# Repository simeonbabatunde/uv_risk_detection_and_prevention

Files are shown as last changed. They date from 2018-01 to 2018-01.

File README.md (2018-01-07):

### UV Risk Detection and Alert System

#### Team UV
- Kristopher Kohm
- Simeon Babatunde
- Benjamin Coomes
- Miriam Lozneanu

#### System Description
The UV risk detection and alert system is a set of wearable devices that inform the user about UV exposure rate. One device senses UV radiation and the other displays the UV radiation levels. The display device shows the current and average UV index. The display is in the form of two LED bars that ‘fill up’ as exposure increases, and ‘empty’ as exposure decreases. The sensor device can be clipped onto a hat or backpack. The display device is worn on the user’s wrist. The system lets people know when they have experienced a healthy amount of radiation and when their exposure is approaching dangerous levels.

#### Image(s)
skype_picture 1

October 3, 2017

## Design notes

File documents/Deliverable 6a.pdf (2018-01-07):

Team | UV | - | Final | Report
Simeon Babatunde | sbabatu@g.clemson.edu
Benjamin Coomes | bcoomes@g.clemson.edu
Kristopher Kohm | kckohm@g.clemson.edu
Miriam Lozneanu | mloznea@g.clemson.edu
Project | Summary

Our system is a set of wearable devices that inform the user about UV exposure. One device senses UV radiation and the other displays UV radiation levels. The display device shows the current and average UV index. The display is in the form of two LED bars that ‘fill up’ as exposure increases, and ‘empty’ as exposure decreases. The sensor device can be clipped onto a hat or backpack. The display device is worn on the user’s wrist. Our system lets people know when they have experienced a healthy amount of radiation and when their exposure is approaching dangerous levels.

Project | Description | and | Implementation

Changes
- Battery - Originally the batteries for each component were going to be a series of coin cell batteries. This was changed to the Lithium Ion batteries used for the final project for three reasons, the first of which was rechargeability. Once the coin cell batteries ran out of power they would need to be replaced, but the Lithium Ion batteries could simply be recharged. The second reason was that we wanted an extra 0.1 Volts from our battery which the Lithium Ion batteries offered. The final reason was the capacity of the batteries, because the coin cell batteries would not have lasted nearly as long as the Lithium Ion batteries. The coin cell batteries offered 110mAh at 3.6 Volts, whereas the Lithium Ion batteries offered 1000 mAh at 3.7 Volts.
- Sensor Device Displays - Originally one of the sensor bars was supposed to display the instantaneous changes in UV levels and the other was supposed to display the total amount of radiation received since the device had been on. The instantaneous bar was kept the same, but the total bar was changed to an average amount of radiation received since the sensor device had been on. This was both more useful and computationally efficient because we did not have to worry about overflow from the total.

Software:
- Sensor Board - The sensor board runs a program that loops between three states: get UV index, compute average UV index, and transmit data. The UV index is calculated based on values read from the UV sensor. We found the algorithm to calculate the UV index as a part of the Sparkfun software library for the ZOPT2201 UV sensor. After getting the current UV index, it is used to calculate the average UV index from the time the sensing device has been on. Once the instantaneous and average UV index have been obtained, they are sent to the sensor board. Each message sent is only two bytes. The first byte contains the current UVI and the second contains the average UVI. Transmission is done using Josiah Hester’s CC1101 library.
- Display Board - The display board checks to see if any radio transmissions have been received every 100 ms. If a message has been received, the current UVI is retrieved from the first byte and the average UVI is retrieved from the second byte. The program then sets the LEDs on each LED bar according to the values received. We wrote an LedBar class to simplify controlling each LED bar.

Hardware
The following is the list of electronic components used in the implementation of our system:
- ZOPT2201 UV Sensor: this component was used in the sensing unit for sensing 310nm ultraviolet radiation (UVB). It gives accurate UV index measurement without interpolation from ambient light like most other sensors. It utilizes simple I

2C (Inter-Integrated Circuit) interface for communicating with the MSP430fr5969 microcontroller, and rated for 3.3V and 110μA. It uses dual Qwiic connectors for seamless connection.
- MSP430FR5969 Microcontroller: This is the major component used in both the sensing and display unit of the system. It is an ultra-low-power (ULP) FRAM platform, utilizing 16-bit RISC Architecture for up to 16-MHz clock. It is responsible for controlling and interfacing with other peripherals within the system. Powered by (1.8 V to 3.6 V) and consumes approximately 100µA/MHz. The first Microcontroller is responsible for fetching the sensed data from the UV sensor, compute the average UVB index and then transmit the data to the display unit via the CC1101 radio transceiver. The second microcontroller is responsible for retrieving transmitted data from the radio transceiver and then drives the display section based on the signals received.
- CC1101 Radio Transceiver: It is a low-cost sub-1GHz transceiver designed for very low-power wireless applications. It was used for initiating remote data transfer between the sensing and display module. It interfaces with both microcontrollers and operates in the frequency range 387 – 464 MHz with instantaneous maximum working current less than 30mA. It interfaces with the MSP430 microcontroller using Serial Peripheral Interface Bus (SPI).
- YSLB-10251B5-10 LED bar: This is a simple strip of 10 blue LEDs. Each LED is controlled directly by the microcontroller via the IO pins. Each LED operated between 3.2 and 3.6 V, with a maximum forward current of 20mA. We used two of these on our display board to indicate the current and average UV index. We used 330 Ohm resistors to drop the current to 10mA on each LED.
- Li-Ion Battery PRt-13813: These rechargeable Lithium Ion batteries offered 1000 mAh at 3.7 Volts. These were connected to the Vin pin of the Voltage Regulator which converts it into 3.3V. One was supplied for each unit and they could easily be attached and removed via headers on each board.
- NCP583 LDO Voltage Regulator: This was used on both units to regulate the 3.7V from the battery into 3.3V used to power the components.
- Resistor: We utilized a 330 ohms resistor for limiting the LED current to 10mA. Thus, minimizing the energy consumption of the system.
- Capacitor: We used both 1µF and 0.1µF as filtering capacitors at the input and output of the voltage regulator on both units.
- Surface Mount DPDT Switch: the switch was used as the main controller for switching the system ON/OFF. It is capable of switching up to 360mA at 3.3v.
Board | Pictures:

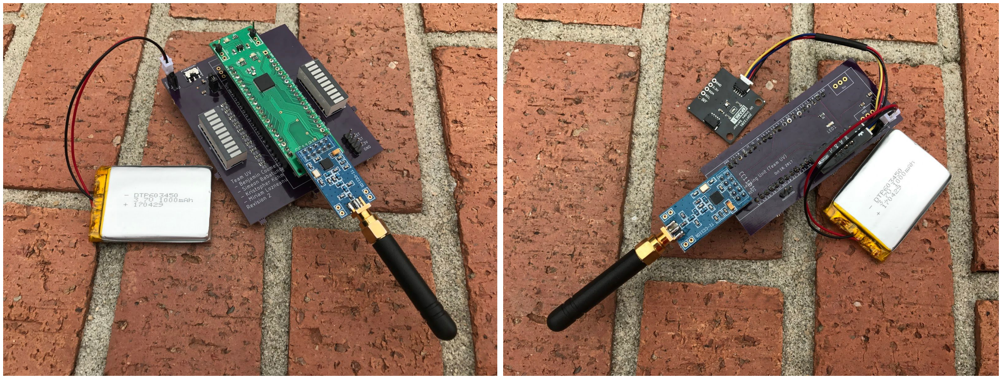
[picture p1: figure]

Display Board | Sensor Board

Challenges:
- Radios: The biggest challenge we faced during demonstrations was reliable radio communication. We did not perform any checks on received data, so interference and corrupted packets could cause our display device to malfunction. We could have solved this problem by establishing a session between the display and sensor boards before either begins sending or receiving data. A session key would be chosen and appended to the first byte of every message. Messages without this key would be ignored. We also should have checked the values of the UV indexes, and ignored any invalid values.
- Pin configurations: We wanted to use the green MSP430 boards since they already has an MSP430 chip soldered to them, as well as a place for the
CC1101 radio. However, we discovered that pin 3.6 was wired to the radio on the green board. We needed this pin for I2C communication with the UV sensor. We managed to move the pin by modifying the pins.h file in Josiah Hester’s CC1101 library. We also had to change Energia.h under energia-1.6.10E18\hardware\energia\msp430\cores\msp430 to add pin definitions to energia, since the green board exposes some pins that Energia does not define.

Resources
- Josiah Hester’s CC1101 library: This library provides a simple interface to the CC1101 radios that we used in our project. It can be found at the following buffet
repository: | https://buffet.cs.clemson.edu/vcs/u/jhester/cc1101-energia/. | We
modified the pin configuration slightly for the sensor board, since the library uses pin 3.6 by default, which we needed for the ZOPT2201 UV sensor. We also referred to the TX and RX examples included in this library when writing code for our devices.
- ZOPT2201 library: This library was developed by Nathan Seidle at Sparkfun. It contain the firmware and sample code for interfacing the ZOPT2201 UV sensor with the microcontroller via the I2C protocol. We customized the library by creating a .cpp version for energia which also contains the logic for computing the UVB average. The library can be found here: https://github.com/sparkfunX/Qwiic_UV_Sensor-ZOPT220x/tree/master/Firmwar e (https://github.com/sparkfunX/Qwiic_UV_Sensor-ZOPT220x/tree/master/Firmware)
Class | Feedback
What | was | the | most | challenging | part | of | this | class?
Ben: The most mentally challenging part was learning how to select parts that would work together and designing a circuit to connect them. The most challenging part overall was putting the accelerometer on the sensor board.

Simeon: The class on state machines and low power modes took me some time to comprehend.
Kristopher: Constructing a properly functioning sensor board (for the class, not the project) was fairly difficult. In addition, working with hardware for the first time is daunting coming from a Computer Science background.

Miriam: I used light traffic examples, but coding was hard for me. I tried to figure out how to get files on Energia working, but that was difficult too.

What | would | you | like | to | see | added | to | this | class | in | future | semesters?
Ben: I would like to see more pizza on demo day. Other than that, I can’t think of anything else to add.

Simeon: I would appreciate if a deadline is set earlier on in the semester for the assembling of the sensor board before taking the class on Accelerometry and signal processing. Also, having accelerometer with a bigger footprint would be fun to assemble.

Kristopher: I would like to do more hands on, in class demonstrations and activities. Perhaps more of them could rely on use of the red boards instead of the sensor boards in case people had trouble with them.

Miriam: I am interested in solar energy, and like to learn about it.

Free | response | on | the | class | in | general.
Ben: This was a fun and practical class. I think that I could build other similar embedded systems on my own now. Before this semester, I would have been too intimidated by putting hardware together to try.

Simeon: The class does not only cover the technical aspect of Embedded Systems, but also helps in developing interpersonal skills like teamwork, presentation, and creative thinking.

Kristopher: I appreciated not having to stress about exams in this class because that made it much more enjoyable to come to. Also, the Computer Science major does not offer many practical applications of hardware combined with software, so it was beneficial to see how these two important elements could come together.

Miriam: I enjoyed the class so far, and it gave me an great opportunity to learn about hardware and software.

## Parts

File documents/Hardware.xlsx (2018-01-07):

Name | VMAX | VMIN | I | URL | Price | Qty | total | Description/Notes
Qwicc UV Sensor - ZOPT2201 | 3.6V | 1.7V | .110 mA | https://www.sparkfun.com/products/14264 | $9.95 | 1 | 9.95 | UVB and ambient light sensing. Needs qwiic connections. 3.3V, I2C interface.
Coin Cell Battery 3.6v |  |  |  | https://www.sparkfun.com/products/10319 | $2.95 | 4 | 11.8 | 110mAh, rechargeable, each MCU will need one, and we want a spare for each MCU
Coin Cell Battey Holder |  |  |  | https://www.sparkfun.com/products/8863 | $0.95 | 2 | 1.9 | One for each battery
Li-Ion Battery PRt-13813 |  |  | 1000mAh
MSP430 MCU | 3.6V | 1.8V | 2.5mA | ?? | $0.00 | 2 | 0 | We will use the msp430s on the small green pcb
10 Segment LED Bar Graph | 3.6V | 3.2V | 20 mA | https://www.sparkfun.com/products/9937 | $1.95 | 2 | 3.9 | 3.2-2.6 V, used for output from UV sensor one blue one green
cc1101 Transciever | 3.6V | 1.8V | 15-40 mA | https://www.amazon.com/dp/B00U5TO37W?creative=395033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 | $15.40 | 2 | 30.8 | For radio communication
NCP583 | 6V |  |  | http://www.mouser.com/search/ProductDetail.aspx?r=863-NCP583SQ33T1G
100mm qwiic cable |  |  |  | https://www.sparkfun.com/products/14427 | $2.00 | 1 | 2 | for connecting the UV sensor to the board
qwiic adapter |  |  |  | https://www.sparkfun.com/products/14237 | $0.95 | 1 | 0.95 | qwiic to I2C conversion
Officemate Binder Clips |  |  |  | https://www.amazon.com/Officemate-Binder-Clips-Assorted-31022/dp/B007TR2DLG | $4.75 | 1 | 4.75 | For attaching components to any hat
Surface mount DPDT Switch |  |  |  | https://www.sparkfun.com/products/597 | $1.50 | 2 | 3 | For Switching the Device ON/OFF
UV Lamp |  |  |  |  |  |  | 0 | Required for simulating UV radiation source
Resistors |  |  |  |  |  |  | 0
 |  |  |  |  |  |  | 0
 |  |  |  |  |  |  | 0
 |  |  |  |  |  |  | 0
 |  |  |  |  |  |  | 0
 |  |  |  |  |  |  | 0
 |  |  |  | TOTAL | 69.05
 |  | battery (mAh) | 1000
 |  | msp430 | 2.5
 |  | leds | 40
 |  | cc1101 | 40 | 82.5
 |  | hours | 12.12121212

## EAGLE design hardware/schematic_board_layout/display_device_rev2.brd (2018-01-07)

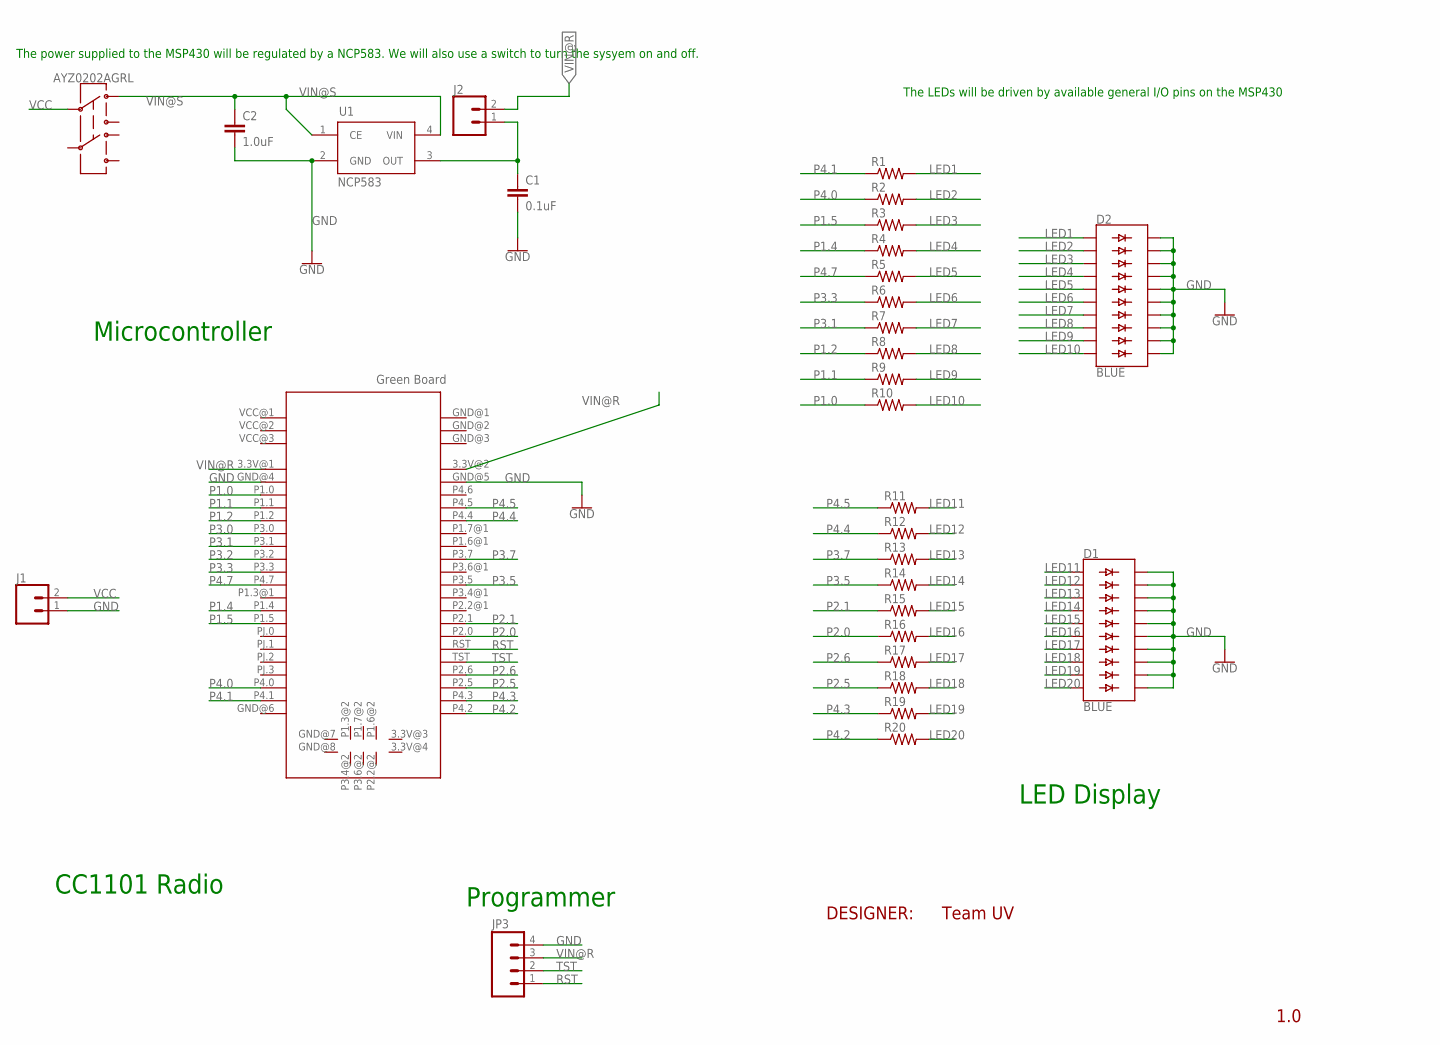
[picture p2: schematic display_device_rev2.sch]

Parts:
AYZ0202AGRL: SWITCH-DPDT-SMD-AYZ0202; SWITCH_DPDT_SMD_AYZ0202
C1: 0.1uF; 0805
C2: 1.0uF; 0805
D1, D2: BLUE; LED_BARGRAPH_10
J1, J2: CONN_02; 1X02
JP3: M04PTH; 1X04
R1, R2, R3, R4, R5, R6, R7, R8, R9, R10, R11, R12, R13, R14, R15, R16, R17, R18, R19, R20: R-US_R0805; R0805
U1: NCP583; SC82-AB_1PRIMARY
U$1: GREEDNBRD; GREENBRD

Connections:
GND: C1.2, C2.2, D1.11 (C9), D1.12 (C8), D1.13 (C7), D1.14 (C6), D1.15 (C5), D1.16 (C4), D1.17 (C3), D1.18 (C2), D1.19 (C1), D1.20 (C), D2.11 (C9), D2.12 (C8), D2.13 (C7), D2.14 (C6), D2.15 (C5), D2.16 (C4), D2.17 (C3), D2.18 (C2), D2.19 (C1), D2.20 (C), J1.1, JP3.4, U1.2 (GND), U$1.GND@4 (GND), U$1.GND@5 (GND)
LED1: D2.1 (A), R1.2
LED2: D2.2 (A1), R2.2
LED3: D2.3 (A2), R3.2
LED4: D2.4 (A3), R4.2
LED5: D2.5 (A4), R5.2
LED6: D2.6 (A5), R6.2
LED7: D2.7 (A6), R7.2
LED8: D2.8 (A7), R8.2
LED9: D2.9 (A8), R9.2
LED10: D2.10 (A9), R10.2
LED11: D1.1 (A), R11.2
LED12: D1.2 (A1), R12.2
LED13: D1.3 (A2), R13.2
LED14: D1.4 (A3), R14.2
LED15: D1.5 (A4), R15.2
LED16: D1.6 (A5), R16.2
LED17: D1.7 (A6), R17.2
LED18: D1.8 (A7), R18.2
LED19: D1.9 (A8), R19.2
LED20: D1.10 (A9), R20.2
P1.0: R10.1, U$1.P1.0
P1.1: R9.1, U$1.P1.1
P1.2: R8.1, U$1.P1.2
P1.4: R4.1, U$1.P1.4
P1.5: R3.1, U$1.P1.5
P2.0: R16.1, U$1.P2.0
P2.1: R15.1, U$1.P2.1
P2.5: R18.1, U$1.P2.5
P2.6: R17.1, U$1.P2.6
P3.0: U$1.P3.0
P3.1: R7.1, U$1.P3.1
P3.2: U$1.P3.2
P3.3: R6.1, U$1.P3.3
P3.5: R14.1, U$1.P3.5
P3.7: R13.1, U$1.P3.7
P4.0: R2.1, U$1.P4.0
P4.1: R1.1, U$1.P4.1
P4.2: R20.1, U$1.P4.2
P4.3: R19.1, U$1.P4.3
P4.4: R12.1, U$1.P4.4
P4.5: R11.1, U$1.P4.5
P4.7: R5.1, U$1.P4.7
RST: JP3.1, U$1.RST
TOPIN: C1.1, J2.1, U1.3 (OUT)
TST: JP3.2, U$1.TST
VCC: AYZ0202AGRL.2, J1.2
VIN@R: J2.2, JP3.3, U$1.3.3V@1 (3.3V), U$1.3.3V@2 (3.3V)
VIN@S: AYZ0202AGRL.1, C2.1, U1.1 (CE), U1.4 (VIN)

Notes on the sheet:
The LEDs will be driven by available general I/O pins on the MSP430
The power supplied to the MSP430 will be regulated by a NCP583. We will also use a switch to turn the sysyem on and off.
DESIGNER:
Team UV
1.0
Microcontroller
CC1101 Radio
Programmer
LED Display

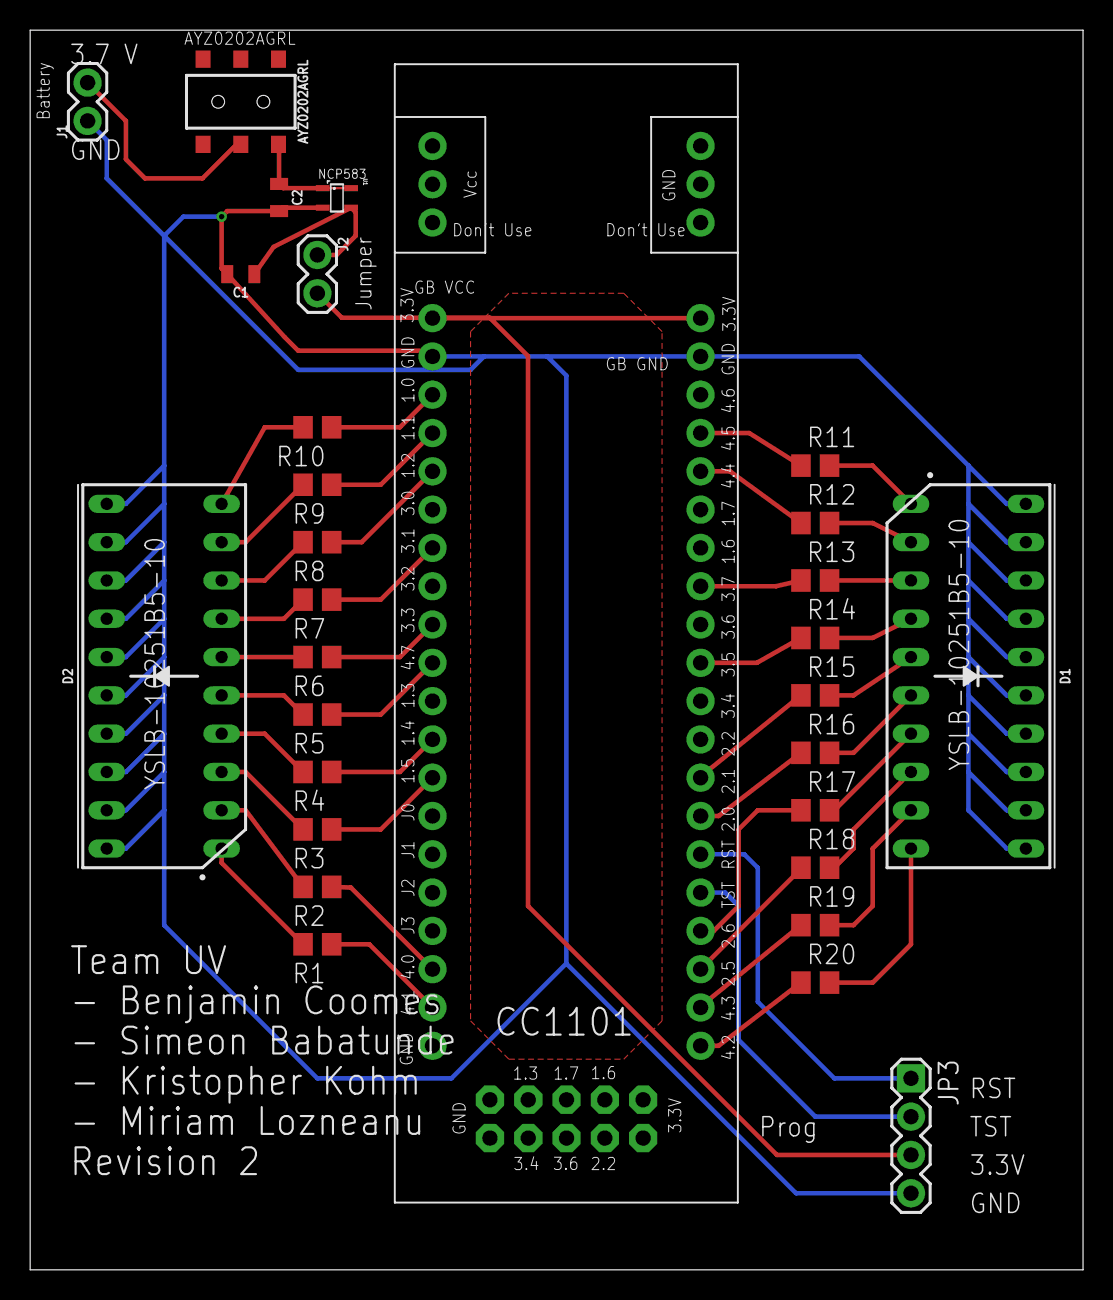
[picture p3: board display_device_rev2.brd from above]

Board: 2 copper layers, 69.8 x 82.2 mm, 30 parts (0 on the bottom side), 47 nets.

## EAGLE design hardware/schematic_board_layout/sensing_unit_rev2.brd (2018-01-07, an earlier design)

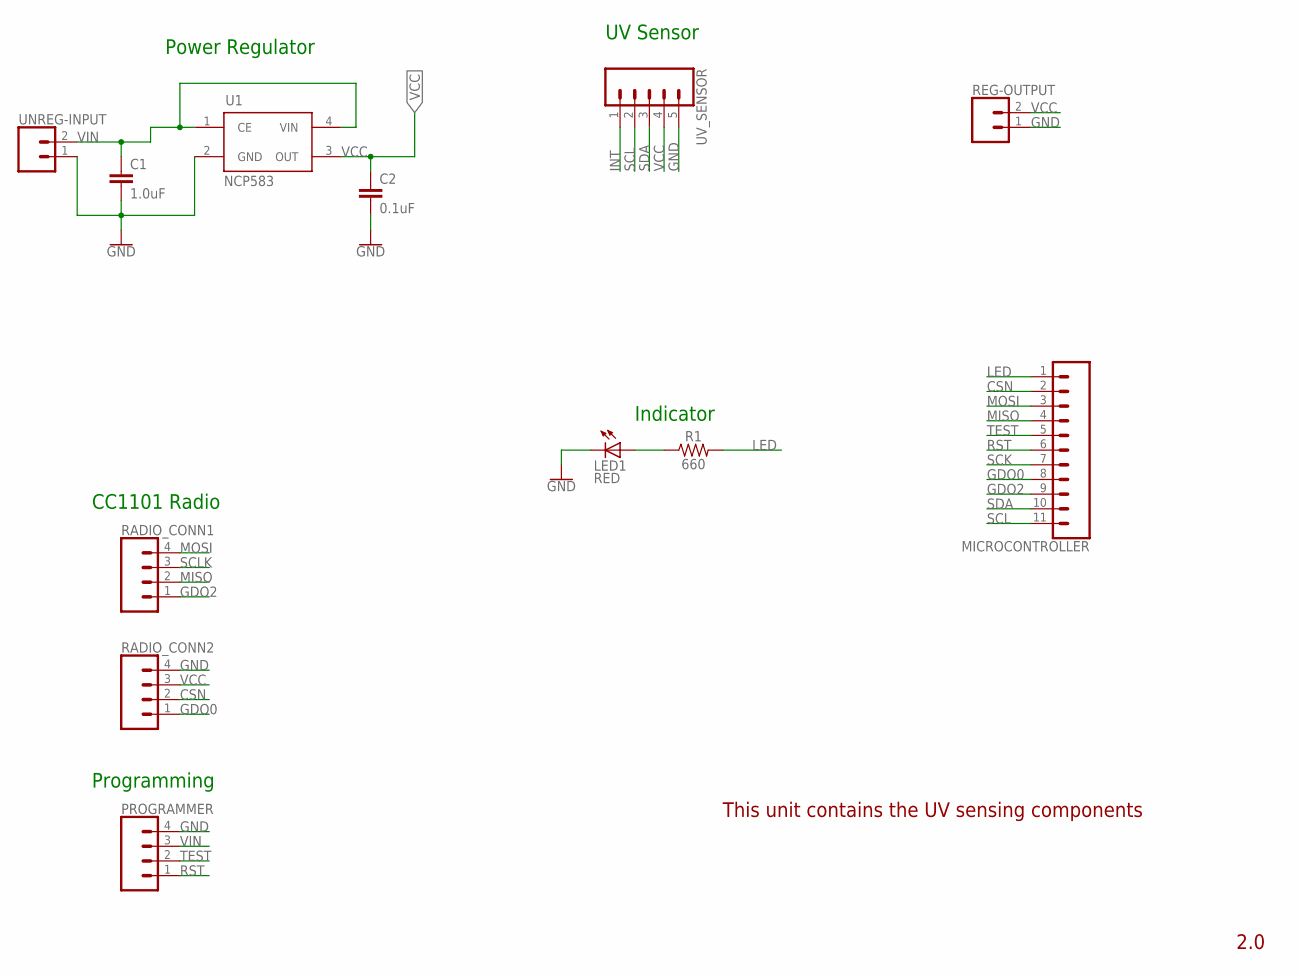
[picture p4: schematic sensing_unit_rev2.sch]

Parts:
C1: 1.0uF; 0805
C2: 0.1uF; 0805
LED1: RED; CHIP-LED0805
MICROCONTROLLER: CONN_11; 1X11
PROGRAMMER: CONN_04; 1X04
R1: 660; 0805
RADIO_CONN1, RADIO_CONN2: CONN_04; 1X04
REG-OUTPUT: CONN_02; 1X02
U1: NCP583; SC82-AB_1PRIMARY
UNREG-INPUT: CONN_02; 1X02
UV_SENSOR: CONN_05; 1X05

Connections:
CSN: MICROCONTROLLER.2, RADIO_CONN2.2
GDO0: MICROCONTROLLER.8, RADIO_CONN2.1
GDO2: MICROCONTROLLER.9, RADIO_CONN1.1
GND: C1.2, C2.2, LED1.C, PROGRAMMER.4, RADIO_CONN2.4, REG-OUTPUT.1, U1.2 (GND), UNREG-INPUT.1, UV_SENSOR.5
INT: UV_SENSOR.1
LED: MICROCONTROLLER.1, R1.2
MISO: MICROCONTROLLER.4, RADIO_CONN1.2
MOSI: MICROCONTROLLER.3, RADIO_CONN1.4
unnamed: LED1.A, R1.1
RST: MICROCONTROLLER.6, PROGRAMMER.1
SCK: MICROCONTROLLER.7
SCL: MICROCONTROLLER.11, UV_SENSOR.2
SCLK: RADIO_CONN1.3
SDA: MICROCONTROLLER.10, UV_SENSOR.3
TEST: MICROCONTROLLER.5, PROGRAMMER.2
VCC: C2.1, RADIO_CONN2.3, REG-OUTPUT.2, U1.3 (OUT), UV_SENSOR.4
VIN: C1.1, PROGRAMMER.3, U1.1 (CE), U1.4 (VIN), UNREG-INPUT.2

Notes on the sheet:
2.0
Power Regulator
UV Sensor
Indicator
CC1101 Radio
Programming
This unit contains the UV sensing components

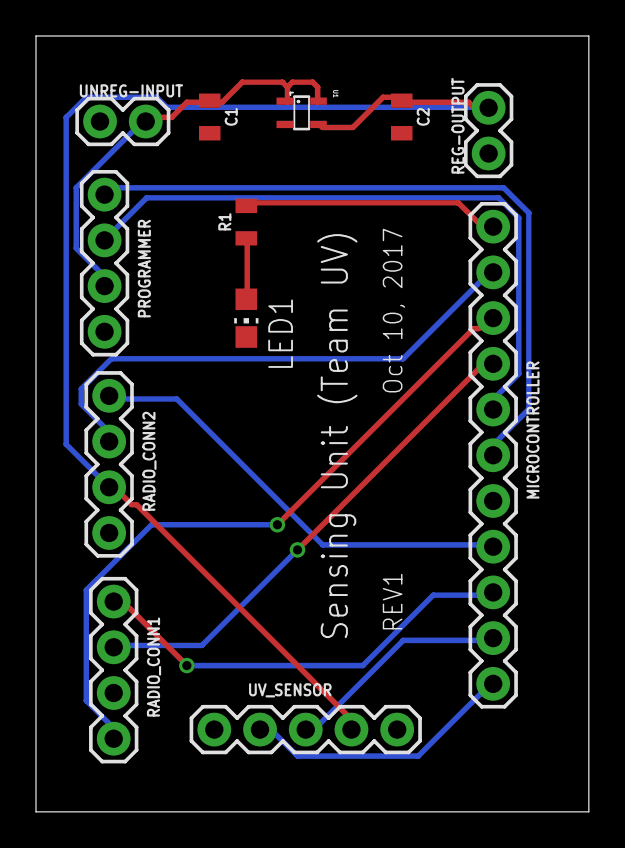
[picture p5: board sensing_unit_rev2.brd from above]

Board: 2 copper layers, 30.7 x 43.1 mm, 12 parts (0 on the bottom side), 14 nets.

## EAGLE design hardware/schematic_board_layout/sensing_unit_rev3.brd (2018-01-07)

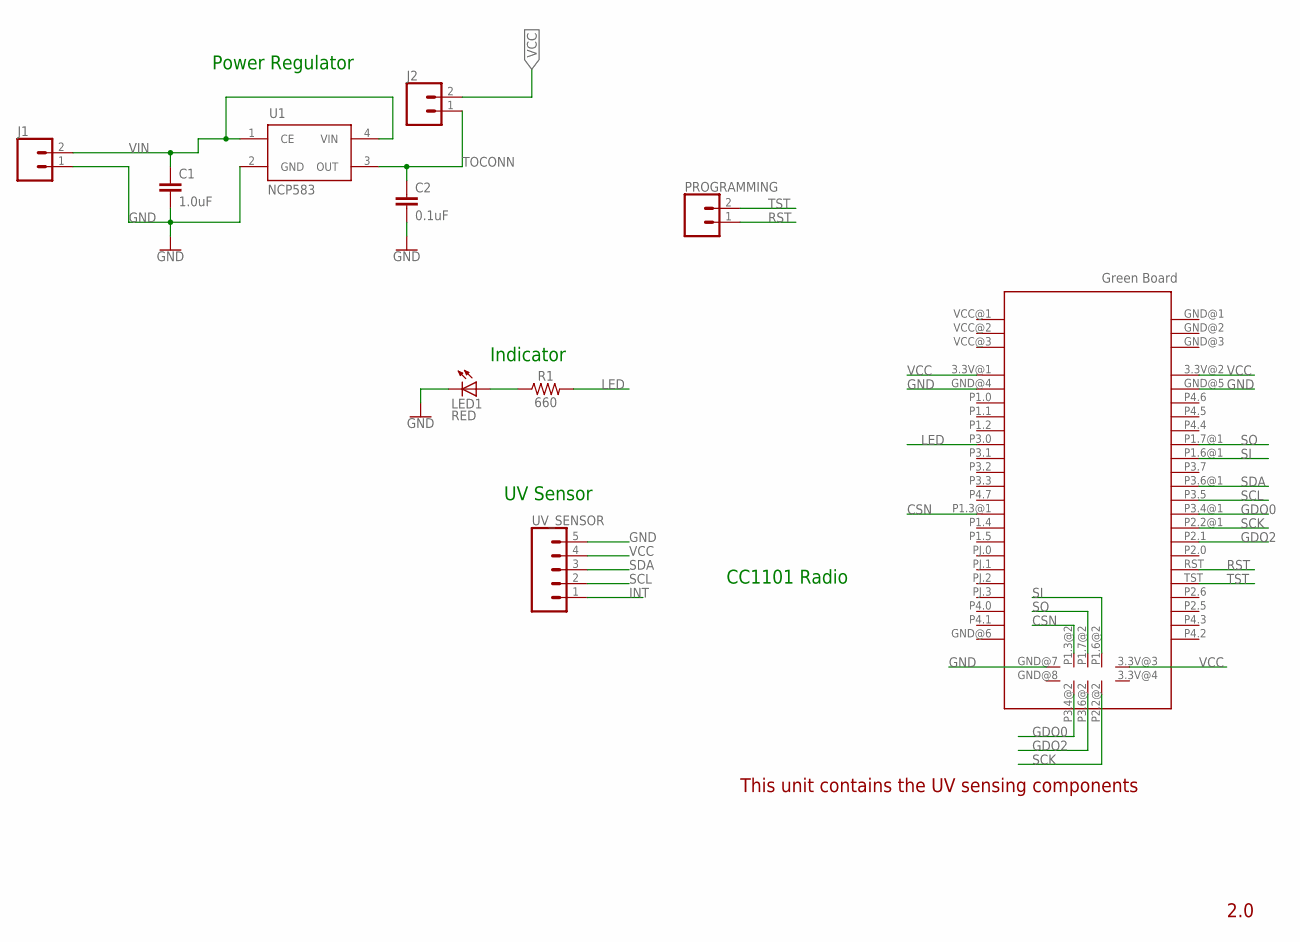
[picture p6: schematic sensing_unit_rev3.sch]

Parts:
C1: 1.0uF; 0805
C2: 0.1uF; 0805
J1, J2: CONN_02; 1X02
LED1: RED; CHIP-LED0805
PROGRAMMING: CONN_02; 1X02
R1: 660; 0805
U1: NCP583; SC82-AB_1PRIMARY
U$1: GREEDNBRD; GREENBRD
UV_SENSOR: CONN_05; 1X05

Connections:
CSN: U$1.P1.3@1 (P1.3), U$1.P1.3@2 (P1.3)
GDO0: U$1.P3.4@1 (P3.4), U$1.P3.4@2 (P3.4)
GDO2: U$1.P2.1, U$1.P3.6@2 (P3.6)
GND: C1.2, C2.2, J1.1, LED1.C, U1.2 (GND), U$1.GND@4 (GND), U$1.GND@5 (GND), U$1.GND@7 (GND), UV_SENSOR.5
INT: UV_SENSOR.1
LED: R1.2, U$1.P3.0
unnamed: LED1.A, R1.1
RST: PROGRAMMING.1, U$1.RST
SCK: U$1.P2.2@1 (P2.2), U$1.P2.2@2 (P2.2)
SCL: U$1.P3.5, UV_SENSOR.2
SDA: U$1.P3.6@1 (P3.6), UV_SENSOR.3
SI: U$1.P1.6@1 (P1.6), U$1.P1.6@2 (P1.6)
SO: U$1.P1.7@1 (P1.7), U$1.P1.7@2 (P1.7)
TOCONN: C2.1, J2.1, U1.3 (OUT)
TST: PROGRAMMING.2, U$1.TST
VCC: J2.2, U$1.3.3V@1 (3.3V), U$1.3.3V@2 (3.3V), U$1.3.3V@3 (3.3V), UV_SENSOR.4
VIN: C1.1, J1.2, U1.1 (CE), U1.4 (VIN)

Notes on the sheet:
2.0
Power Regulator
UV Sensor
Indicator
CC1101 Radio
This unit contains the UV sensing components

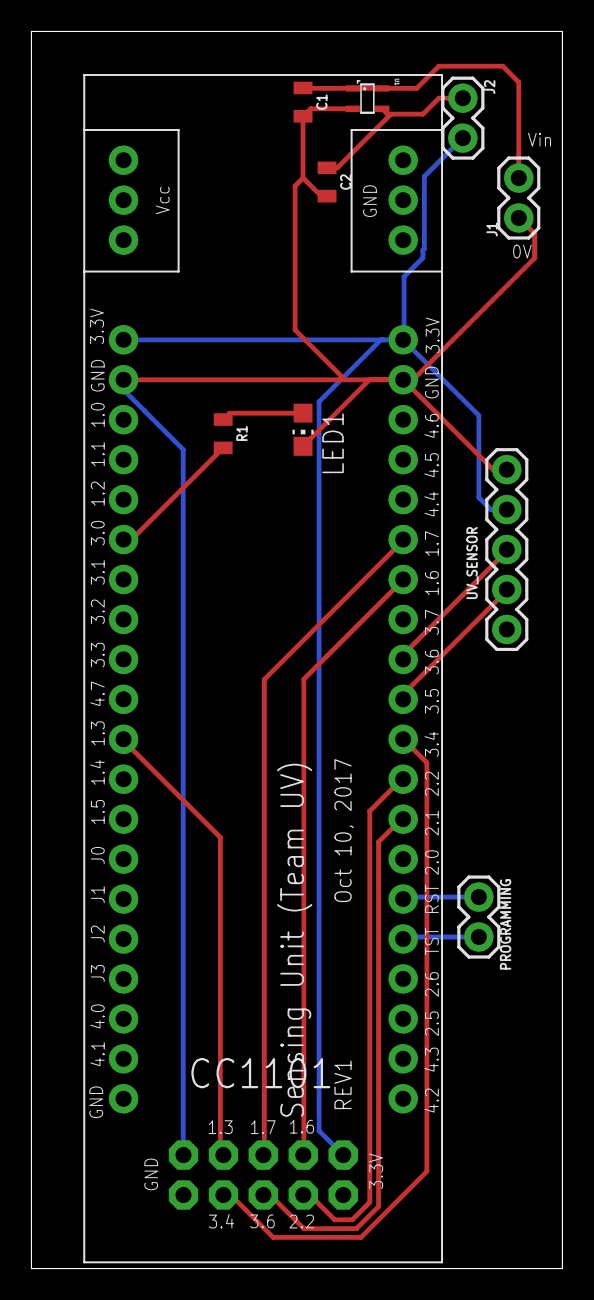
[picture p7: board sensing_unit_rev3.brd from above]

Board: 2 copper layers, 33.8 x 78.7 mm, 10 parts (0 on the bottom side), 16 nets.

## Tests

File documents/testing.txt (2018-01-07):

TEAM UV
- Kristopher Kohm
- Benjamin Coomes
- Simeon Babatunde
- Miriam Lozneanu

TESTING INSTRUCTIONS

Test locations
	Unit tests are in team-uv/software/unit_tests.
	Integration tests are in team-uv/software/integration_tests

Unit Tests
	display_unit_test: Tests the state machine for the display device.
		Purpose: Verify that the display state machine functions correctly.
		HW requirements: 1 MSP430
		
		Open display_unit_test.ino file in energia and run it.
		No configuration required. 
		Test results are printed on command line.

	sensor_state_test: Tests the state machine for the sensor device.
		Purpose: Verify that the sensor state machine functions correctly.
		HW requirements: 1 MSP430
		
		Open the sensor_state_test.ino file in energia and run it. 
		No configuration required. 
		Test results are printed on command line.

	ledbar_test: Tests the interface to the LED bar.
		Purpose: Verify that the led hardware can be controlled by the LedBar class.
		HW requirements: 1 MSP430
		
		Open the ledbar_test.ino file in energia.
		Connect the pins on your MSP430 as described in the file.
		This will test that the input pins are correctly set when
		controlled through the LED interface.
		Upload the file. Test results are printed on command line.

	uv_tranmit_2 and uv_receive_test
		Purpose: Verify that UV data can be transmitted and recieved accurately. 
		HW requirements: 2 MSP430 boards and 2 cc1101 radios.
		
		Open the uv_transmit_2.ino file in energia.
		Wire the one cc1101 radio to one board, as described in the cc1101 repo.
		Upload the file. See uv_receive_test for results.

		Open the uv_receive_test.ino file in energia.
		Wire the other cc1101 radio to the other board, as described in the cc1101 repo.
		Upload the file. Test results are printed on the command line.

	uv_sensor_test
		Purpose: Verify that the sensor transmits reasonable UV values.
		HW requirements: 1 MSP430 board and 1 ZOPT2201 UV sensor

		Open the uv_sensor_test.ino file.
		Wire the sensor as described at the top of the file.

Integration Tests
	radio_lights: Tests the LED interface, hardware, and radio communication together.
		HW requirements: 2 MSP430 boards, 2 CC1101 radios, and 10 LEDs

		Open the radio_lights/display/display.ino file in energia.
		Wire each LED to the pin it is '#-defined' as. 
		Arrange the LEDs in sequential order to make viewing test results easy.
		Wire the CC1101 as described in the CC1101 repo.
		Upload the file. 
		Lights on LEDs should turn on in the pattern defined in sensor.ino.

		Open the radio_lights/sensor/sensor.ino file in energia.
		Wire the CC1101 as described in the CC1101 repo.
		Upload the file. 
		See the pseudoGetUVIndex() function to see what values are transmitted.

	uv_radio_lights: Test the entire system.
		HW requirements: 2 MSP430 boards, 2 CC1101 radios, and 1 ZOPT2201 UV Sensor

		Open the uv_radio_lights/display/display.ino file in energia.
		Wire the CC1101 as described in the CC1101 repo.
		Upload the file. 
		Values from the UV sensor should be displayed in the serial console.

		Open the uv_radio_lights/sensor/sensor.ino file in energia.
		Wire the ZOPT2201 as described in the uv_radio_lights/uv_radio_
		Wire the CC1101 as described in the CC1101 repo.
		Upload the file. 

Problems: 

	We cannot get the radio code to work inside of a C++ class. For this reason, we
	are unable to create classes to simplfy the radio interface or to use our state 
	machines.

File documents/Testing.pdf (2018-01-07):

Team UV
Repository: https://buffet.cs.clemson.edu/vcs/u/sbabatu/team_uv/ Simeon Babatunde
Benjamin Coomes
Kristopher Kohm
Miriam Lozneanu

Testing
Overview
To ensure the functionality of our system we plan on testing components both individually and as a whole. In addition, we would like to test not just our custom hardware but also the parts we ordered.

LED lights were added to each of the boards to ensure that, at the very least, they were getting power. This will be a quick indication of whether the boards are functioning at a basic level when we receive them because by attaching the custom boards to a power supply we can see if the LEDs turn on.

In addition, there are input pins on each of the boards to make it easy to attach the lithium ion batteries. One of the input pins is for the positive end of the battery and the other for the negative end.

Testing will proceed as follows.

Custom Board
It is of paramount importance to ensure that there is no short circuiting occurring between the traces on the board. To check for this we will carry out an extensive continuity test on the copper traces. This will enable us to detect any form of discontinuity or short circuiting across the copper traces. The Multimeter will be set to continuity and the probes placed on different sections of the custom board. The additional pin headers on the custom board will help in checkpointing the voltage level on the associated component part. This will ensure a seamless connection to the breadboard while troubleshooting specific parts.

LED Bars
In order to avoid soldering multiple times we will test the LED Bars before attaching them to our board. This will be accomplished by wiring the LEDs through a breadboard. Each LED on the bar is individual so each one will need to be checked separately; in addition, we will need to attach the appropriate resistors to the board as well which will have a resistance of 330 ohms. The power supply will be the lithium ion batteries we will be using for the final product.

Voltage Regulator
Because the voltage regulators will need to be attached to the custom boards to complete the circuits we will check the boards voltages after they are attached.

Switch
Much like with the LED Bar we will attach the switch to a breadboard (with a power supply) and put a single LED light in series with it. If we are able to switch the LED on and off then we will know that the switch is functioning properly.

UV Sensor
We will first test the UV Sensor by attaching not to our custom board but our red boards instead. This is so that we can see what kind of output we can read from the sensor in an environment that we can easily change the program running. The sensor will be attached to the redboard using wires (not soldered). We will try exposing the sensor to different levels of UV radiation i.e.:
- Outside in full sunlight
- Outside in the shade
- Outside at night
- Inside during the day

Once we are confident that the sensor is functioning properly, the custom board is working properly, and the voltage regulators are working properly we will solder it to our custom board. We will make sure that the sensor is outputting values and that the values increase in higher sunlight exposure and decrease in lower exposure.

Radio
From using the radios in class activities we should already be confident that they are functioning properly however we will attach the two we will be using to two different redboards and send messages (one as the receiver, one as the transmitter) ensuring their correctness. Then, each radio transmitter will be attached to one of the greenboards before the greenboards are attached to our custom hardware.

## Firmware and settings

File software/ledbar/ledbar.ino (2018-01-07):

#include <msp430.h>
#include "LedBar.h"

#define LED1 P1_5
#define LED2 P1_4
#define LED3 P1_3
#define LED4 P1_7
#define LED5 P1_6
#define LED6 P3_0

/*
int leds[] = {LED1, LED2, LED3, LED4, LED5, LED6};
int ledCount = 6;
int led = 0;
LedBar ledBar(leds, ledCount);
*/

int leds[] = {LED1, LED2, LED3};
int ledCount = 3;
LedBar ledBar(leds, ledCount);

void setup() {
  // put your setup code here, to run once:
  
}

void rangeOfThree(){
  /*
int leds[] = {LED1, LED2, LED3};
int ledCount = 3;
LedBar ledBar(leds, ledCount);
   */

   ledBar.lightRange(0,3);
   delay(1000);
   ledBar.turnOffAll();
   delay(1000);
}

void oneOnOneBlink(){
/*
int leds1[] = {LED1};
int ledCount = 1;
int led1 = 0;
LedBar lb1(leds1, ledCount);

int leds2[] = {LED2};
int led2 = 0;
LedBar lb2(leds2, ledCount);

  
  lb1.lightSingle(led1);
  lb2.lightSingle(led2);
  delay(1000);

  lb1.turnOffAll();
  delay(1000);
*/
}

void loop() {
  // put your main code here, to run repeatedly: 
  rangeOfThree();
  
}

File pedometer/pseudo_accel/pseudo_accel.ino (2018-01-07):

int16_t pa[] = {
-1041,319,-317,
-992,255,-335,
-1040,364,-256,
-1055,208,-265,
-928,144,-336,
-1055,224,-349,
-977,168,-353,
-1121,112,-241,
-1120,359,-144,
-1122,288,8,
-1312,239,80,
-1409,160,-112,
-1457,16,-112,
-1312,123,24,
-896,-41,32,
-856,28,-312,
-993,160,-112,
-1200,204,28,
-1392,168,83,
-1216,160,-303,
-1149,276,-377,
-880,176,-281,
-749,324,-225,
-1032,338,-271,
-1312,435,-112,
-1591,164,-290,
-1408,-33,-440,
-913,-48,-72,
-720,111,-144,
-941,256,-16,
-1213,160,222,
-1304,332,126,
-1668,119,-288,
-1081,146,-258,
-760,-72,-317,
-744,222,-255,
-1092,359,-80,
-1376,280,-317,
-1625,192,-257,
-1465,-160,-161,
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

int16_t lines = 82;
int16_t currLine = 0;

int16_t x, y, z;
int16_t count = 0;

void setup() {
  // put your setup code here, to run once:
  Serial.begin(9600);
  Serial.println("Starting Trace");
  delay(1000);
}

void readXYZData(int16_t *xp, int16_t *yp, int16_t *zp){
  int16_t n = currLine * 3;
  *xp = pa[n + 0];
  *yp = pa[n + 1];
  *zp = pa[n + 2];

  currLine = (currLine + 1) % lines;
}

void loop() {
  // put your main code here, to run repeatedly: 
  if(count < lines){
    readXYZData(&x, &y, &z); 
    count++;
  }
  
  Serial.print("XVALUE=");
  Serial.print(x);   
  Serial.print("\tYVALUE=");
  Serial.print(y);  
  Serial.print("\tZVALUE=");
  Serial.println(z);  
  delay(100);
}

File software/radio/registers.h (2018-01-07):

#ifndef REGS_h
#define REGS_h

/**
 * Command strobes
 */
#define CC1101_SRES              0x30        // Reset CC1101 chip
#define CC1101_SFSTXON           0x31        // Enable and calibrate frequency synthesizer (if MCSM0.FS_AUTOCAL=1). If in RX (with CCA):
                                             // Go to a wait state where only the synthesizer is running (for quick RX / TX turnaround).
#define CC1101_SXOFF             0x32        // Turn off crystal oscillator
#define CC1101_SCAL              0x33        // Calibrate frequency synthesizer and turn it off. SCAL can be strobed from IDLE mode without
                                             // setting manual calibration mode (MCSM0.FS_AUTOCAL=0)
#define CC1101_SRX               0x34        // Enable RX. Perform calibration first if coming from IDLE and MCSM0.FS_AUTOCAL=1
#define CC1101_STX               0x35        // In IDLE state: Enable TX. Perform calibration first if MCSM0.FS_AUTOCAL=1.
                                             // If in RX state and CCA is enabled: Only go to TX if channel is clear
#define CC1101_SIDLE             0x36        // Exit RX / TX, turn off frequency synthesizer and exit Wake-On-Radio mode if applicable
#define CC1101_SWOR              0x38        // Start automatic RX polling sequence (Wake-on-Radio) as described in Section 19.5 if
                                             // WORCTRL.RC_PD=0
#define CC1101_SPWD              0x39        // Enter power down mode when CSn goes high
#define CC1101_SFRX              0x3A        // Flush the RX FIFO buffer. Only issue SFRX in IDLE or RXFIFO_OVERFLOW states
#define CC1101_SFTX              0x3B        // Flush the TX FIFO buffer. Only issue SFTX in IDLE or TXFIFO_UNDERFLOW states
#define CC1101_SWORRST           0x3C        // Reset real time clock to Event1 value
#define CC1101_SNOP              0x3D        // No operation. May be used to get access to the chip status byte

/**
 * CC1101 configuration registers
 */
#define CC1101_IOCFG2            0x00        // GDO2 Output Pin Configuration
#define CC1101_IOCFG1            0x01        // GDO1 Output Pin Configuration
#define CC1101_IOCFG0            0x02        // GDO0 Output Pin Configuration
#define CC1101_FIFOTHR           0x03        // RX FIFO and TX FIFO Thresholds
#define CC1101_SYNC1             0x04        // Sync Word, High Byte
#define CC1101_SYNC0             0x05        // Sync Word, Low Byte
#define CC1101_PKTLEN            0x06        // Packet Length
#define CC1101_PKTCTRL1          0x07        // Packet Automation Control
#define CC1101_PKTCTRL0          0x08        // Packet Automation Control
#define CC1101_ADDR              0x09        // Device Address
#define CC1101_CHANNR            0x0A        // Channel Number
#define CC1101_FSCTRL1           0x0B        // Frequency Synthesizer Control
#define CC1101_FSCTRL0           0x0C        // Frequency Synthesizer Control
#define CC1101_FREQ2             0x0D        // Frequency Control Word, High Byte
#define CC1101_FREQ1             0x0E        // Frequency Control Word, Middle Byte
#define CC1101_FREQ0             0x0F        // Frequency Control Word, Low Byte
#define CC1101_MDMCFG4           0x10        // Modem Configuration
#define CC1101_MDMCFG3           0x11        // Modem Configuration
#define CC1101_MDMCFG2           0x12        // Modem Configuration
#define CC1101_MDMCFG1           0x13        // Modem Configuration
#define CC1101_MDMCFG0           0x14        // Modem Configuration
#define CC1101_DEVIATN           0x15        // Modem Deviation Setting
#define CC1101_MCSM2             0x16        // Main Radio Control State Machine Configuration
#define CC1101_MCSM1             0x17        // Main Radio Control State Machine Configuration
#define CC1101_MCSM0             0x18        // Main Radio Control State Machine Configuration
#define CC1101_FOCCFG            0x19        // Frequency Offset Compensation Configuration
#define CC1101_BSCFG             0x1A        // Bit Synchronization Configuration
#define CC1101_AGCCTRL2          0x1B        // AGC Control
#define CC1101_AGCCTRL1          0x1C        // AGC Control
#define CC1101_AGCCTRL0          0x1D        // AGC Control
#define CC1101_WOREVT1           0x1E        // High Byte Event0 Timeout
#define CC1101_WOREVT0           0x1F        // Low Byte Event0 Timeout
#define CC1101_WORCTRL           0x20        // Wake On Radio Control
#define CC1101_FREND1            0x21        // Front End RX Configuration
#define CC1101_FREND0            0x22        // Front End TX Configuration
#define CC1101_FSCAL3            0x23        // Frequency Synthesizer Calibration
#define CC1101_FSCAL2            0x24        // Frequency Synthesizer Calibration
#define CC1101_FSCAL1            0x25        // Frequency Synthesizer Calibration
#define CC1101_FSCAL0            0x26        // Frequency Synthesizer Calibration
#define CC1101_RCCTRL1           0x27        // RC Oscillator Configuration
#define CC1101_RCCTRL0           0x28        // RC Oscillator Configuration
#define CC1101_FSTEST            0x29        // Frequency Synthesizer Calibration Control
#define CC1101_PTEST             0x2A        // Production Test
#define CC1101_AGCTEST           0x2B        // AGC Test
#define CC1101_TEST2             0x2C        // Various Test Settings
#define CC1101_TEST1             0x2D        // Various Test Settings
#define CC1101_TEST0             0x2E        // Various Test Settings
 
/**
 * Status registers
 */
#define CC1101_PARTNUM           0x30        // Chip ID
#define CC1101_VERSION           0x31        // Chip ID
#define CC1101_FREQEST           0x32        // Frequency Offset Estimate from Demodulator
#define CC1101_LQI               0x33        // Demodulator Estimate for Link Quality
#define CC1101_RSSI              0x34        // Received Signal Strength Indication
#define CC1101_MARCSTATE         0x35        // Main Radio Control State Machine State
#define CC1101_WORTIME1          0x36        // High Byte of WOR Time
#define CC1101_WORTIME0          0x37        // Low Byte of WOR Time
#define CC1101_PKTSTATUS         0x38        // Current GDOx Status and Packet Status
#define CC1101_VCO_VC_DAC        0x39        // Current Setting from PLL Calibration Module
#define CC1101_TXBYTES           0x3A        // Underflow and Number of Bytes
#define CC1101_RXBYTES           0x3B        // Overflow and Number of Bytes
#define CC1101_RCCTRL1_STATUS    0x3C        // Last RC Oscillator Calibration Result
#define CC1101_RCCTRL0_STATUS    0x3D        // Last RC Oscillator Calibration Result
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

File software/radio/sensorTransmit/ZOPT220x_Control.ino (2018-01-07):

byte zoptAddress = 0x53; //Default I2C address. Can be changed via software.
//#define ZOPT220X_ADDR 0x53 //7-bit unshifted default I2C Address
//#define ZOPT220X_ADDR 0x52 //7-bit unshifted programmed NVM I2C Address (in case you need multiple on same bus)

//Register addresses
#define ZOPT220x_MAIN_CTRL 0x00
#define ZOPT220x_LS_MEAS_RATE 0x04
#define ZOPT220x_LS_GAIN 0x05
#define ZOPT220x_PART_ID 0x06
#define ZOPT220x_MAIN_STATUS 0x07
#define ZOPT220x_ALS_DATA 0x0D
#define ZOPT220x_UVB_DATA 0x10
#define ZOPT220x_UV_COMP_DATA 0x13
#define ZOPT220x_COMP_DATA 0x16
#define ZOPT220x_INT_CFG 0x19
#define ZOPT220x_INT_PST 0x1A
#define ZOPT220x_DEVICE_CONFIG 0x2F
#define ZOPT220x_SPECIAL_MODE_1 0x30
#define ZOPT220x_SPECIAL_MODE_2 0x31

#define SENSORTYPE_ZOPT2201 0xB2
#define SENSORTYPE_ZOPT2202 0xB2 //Really IDT!? You didn't use a different part number for different parts?

//Setup the sensor with default settings
//Assume we are using the default zopt address of 0x53
boolean sensorSetup()
{
  boolean result = zopt220xSetupWithAddress(zoptAddress); //Assume the default address
  return (result);
}

//Attempts to talk to sensor. Returns false if sensor is not found
//If found, sets the sensor up with default UVB settings
//Call this function if you've changed the zopt I2C address
boolean zopt220xSetupWithAddress(byte address)
{
  zoptAddress = address; //Do all the zopt I2C communications at this address
  
  byte deviceID = zoptReadRegister(ZOPT220x_PART_ID);
  if (deviceID != 0xB2)
  {
    Serial.print("ID should be 0xB2. We heard 0x");
    Serial.println(deviceID, HEX);
    return (false);
  }

  checkPowerOnStatus(); //Read the POS bit to clear it

  setMeasurementRate(2); //100ms default
  setResolution(0); //20 bit, 400ms, needed for best UVI calculations
  setGain(4); //Default for UVB

  return (true);
}

//Return the current UV index
//Assumes UVB sensor has been setup with default settings
float getUVIndex(void)
{
  byte counter = 0;
  while(!dataAvailable())
  {
    delay(10);
    if(counter++ > 50) //We should have a reading in 400ms
    {
      //We've timed out waiting for the data. Return error
      return(-1.0);
    }
  }

  long uvb = getUVB(); //Get new data
  float uvIndex = getAdjustedUVIndex(uvb, 4, 0); //Assumes default for UVI of gain:4, resolution:0
  return(uvIndex);
}

//Given UVB reading, and gain and resolution settings, outputs UV index
//From App note UV Index Calculation from IDT
float getAdjustedUVIndex(long UVB, byte gain, byte resolution)
{
  byte gainMode = 0; //gain is 0 to 4, gainMode is mapped 1 to 18
  byte resolutionMode = 0; //resolution is 0 to 5, resolutionMode is mapped 20bit to 13bit

  //Convert the 5 gain settings to gainMode
  switch (gain)
  {
    case 0: gainMode = 1; break;
    case 1: gainMode = 3; break;
    case 2: gainMode = 6; break;
    case 3: gainMode = 9; break;
    case 4: gainMode = 18; break;
    default: gainMode = 18; break; //Unknown state
  }

  //Convert the 6 resolution settings to resolutionMode
  switch (resolution)
  {
    case 0: resolutionMode = 20; break; //20-bit
    case 1: resolutionMode = 19; break;
    case 2: resolutionMode = 18; break;
    case 3: resolutionMode = 17; break;
    case 4: resolutionMode = 16; break;
    case 5: resolutionMode = 13; break; //13-bit
    default: resolutionMode = 20; break; //Unknown state
  }

  long uvAdjusted = 18 / gainMode * pow(2, 20 - 20) * UVB;

  //The correction value is default 1. If you want to calculate the actual
  //solar angle you'll need lat/long/day/hh/mm
  float uviCorrection = 1.0;

  //First we need to calculation the elevation angle
  /*float elevationAngle = 

  //Let's calculate the correction!
  float c0 = 3.1543;
  float c1 = -0.06204;
  float c2 = 0.0002186;
  float c3 = 0.0000035516;
  uviCorrection = c0 * pow(elevation, 0);
  uviCorrection += c1 * pow(elevation, 1);
  uviCorrection += c2 * pow(elevation, 2);
  uviCorrection += c3 * pow(elevation, 3);*/  
  
  float uvIndex = uvAdjusted / (5500.0 * uviCorrection);

  return(uvIndex);
}

//Returns the current UV data with temp compensation applied
//Assumes LS data bit 3 has been set (MAIN_STATUS)
//Poll dataAvailable() before calling this function
long getUVB() 
{
  return (zoptRead3Registers(ZOPT220x_UVB_DATA));
}

//Returns the current Ambient Light data with temp compensation applied
//Assumes data is available (LS data bit 3 has been set in MAIN_STATUS)
//Poll dataAvailable() before calling this function
long getALS() 
{
  return (zoptRead3Registers(ZOPT220x_ALS_DATA));
}

//Set the measurement rate
//0 = 25ms per measurement
//1 = 50ms
//2 = 100ms (default)
//3 = 200ms
//4 = 500ms
//5 = 1000ms
//6 = 2000ms
//7 = 2000ms
void setMeasurementRate(byte rate)
{
  if (rate > 7) rate = 7; //Error check

  //Read, set, write
  byte value = zoptReadRegister(ZOPT220x_LS_MEAS_RATE); //Read
  value &= ~(0b00000111); //Clear bits 2/1/0
  value |= rate; //Mask in rate
  zoptWriteRegister(ZOPT220x_LS_MEAS_RATE, value); //Write
}

//Set the measurement resolution
//0 = 20 bit / 400ms
//1 = 19 bit / 200ms
//2 = 18 bit / 100ms (default)
//3 = 17 bit / 50ms
//4 = 16 bit / 25ms
//5 = 13 bit / 3.125ms
void setResolution(byte resolution)
{
  if (resolution > 5) resolution = 5; //Error check

  //Read, set, write
  byte value = zoptReadRegister(ZOPT220x_LS_MEAS_RATE); //Read
  value &= ~(0b01110000); //Clear bits 6/5/4
  value |= (resolution << 4); //Mask in resolution
  zoptWriteRegister(ZOPT220x_LS_MEAS_RATE, value); //Write
}

//Set the gain for the sensor
//Different for ALS and UVB. It depends which mode you're in. See datasheet for info.
//0 = Gain 1
//1 = Gain 3 (default)
//2 = Gain 6
//3 = Gain 9
//4 = Gain 18 (recommended for UBV)
void setGain(byte gain)
{
  if (gain > 4) gain = 4; //Error check

  //Read, set, write
  byte value = zoptReadRegister(ZOPT220x_LS_GAIN); //Read
  value &= ~(0b00000111); //Clear bits 2/1/0
  value |= gain; //Mask in gain
  zoptWriteRegister(ZOPT220x_LS_GAIN, value); //Write
}

//Returns true if Bit 5 is set
boolean checkPowerOnStatus()
{
  byte value = zoptReadRegister(ZOPT220x_MAIN_STATUS); //Read
  if (value & 1 << 5) return (true);
  return (false);
}

//Check if new data is available
//Returns true if Bit 3 is set
boolean dataAvailable()
{
  byte value = zoptReadRegister(ZOPT220x_MAIN_STATUS); //Read
  if (value & 1 << 3) return (true);
  return (false);
}

//Turns on sensor
//Sets LS_EN bit
void enableSensor(void)
{
  //Read, set, write
  byte value = zoptReadRegister(ZOPT220x_MAIN_CTRL); //Read
  value |= (1 << 1); //Set LS_EN bit
  zoptWriteRegister(ZOPT220x_MAIN_CTRL, value); //Write
}

//Turns off sensor
//Clears LS_EN bit
void disableSensor(void)
{
  //Read, set, write
  byte value = zoptReadRegister(ZOPT220x_MAIN_CTRL); //Read
  value &= ~(1 << 1); //Clear LS_EN bit
  zoptWriteRegister(ZOPT220x_MAIN_CTRL, value); //Write
}

void standby() {
  setMode(1);  //Turn off everything and standby for I2C
}
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

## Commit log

2018-01-07 Created a new repo for the project
    [display_device.sch, display_device_for_board.brd, display_device_for_board.sch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]
2018-01-07 Added other documents
    [Hardware.xlsx]

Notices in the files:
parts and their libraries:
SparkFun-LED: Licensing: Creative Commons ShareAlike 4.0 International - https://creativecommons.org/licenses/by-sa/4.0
